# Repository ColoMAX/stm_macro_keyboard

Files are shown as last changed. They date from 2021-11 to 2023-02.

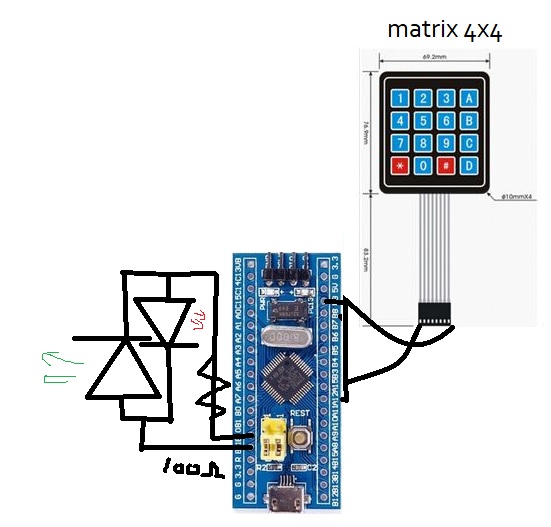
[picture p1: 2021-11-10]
design/draft_schemetic.jpg

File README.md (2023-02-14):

To build needs platformio. Rest can be read in src/main.cpp

Casing just plain PLA and 4 M2 bolts.
Glued some large nuts on the inside to weight down
and some hotglue on the bolts to make it less slippery.

# Building

The macro definitions can be given during the build-process via a cli. Or it can be done via the header file in source.
For the latter the last line of the platformio.ini files needs to be commented out.

It is recommended to use the maple dfu bootloader. In this repo a copy of [maple bootloader](https://github.com/rogerclarkmelbourne/STM32duino-bootloader/blob/df689808b6030280480c0d151ee9c552ecf6b405/binaries/generic_boot20_pc13.bin) is provided.

It is also wise to lock the flash pages using openocd or stlink-utils.

# Operation

settings can be found in `macros_example.hpp`and I recommend changing the timings to your liking.
Device needs stmDuino bootloader.

After the device is flashed and setup it does:
    It first starts the bootloader, after which the red led wil flash (high frequency).
    You may enter a pincode to unlock the device, applying with "*" key.
    If the pincode is correct the green led should light up.
    If wrong, the green and red led should light-up momentarily (orange if led in the same package).
    The pincode can then be retried. After a number of wrong attempts, the device will lockout for some time.
    Then it may be retried. NOTE this lockout can be circumvented once power is lost TODO fix this).
    If then again the attemp limit is reached, the device will wipe its own memory, except of the bootloader.

    If the pincode was correct, the green led will light up.
    Now macros can be used by short pressing any of the buttons, or the device can be switched to numpad mode by a long-press "#".
    One may also whish to go into bootloader mode, then long-hold D. Then de device will restart.
    After some time of inactivity, you will be logged out and the pincode will need to be re-applied.
    This is indicated by the red led starting to flash. You'll get a warning of this timeout by the green led starting to flash.
    You can also manually logout by a long-pres on the "*" button.

    The login timeout can be disabled by going into numpad mode (long-press #) and long-pressing D. The led will momentarily turn green when the timeout is disabled, otherwise red for re-enabled.

# TODO
    Encryption of macros
    use HAL/NVIC
    rewrite pin detection
    write better readme

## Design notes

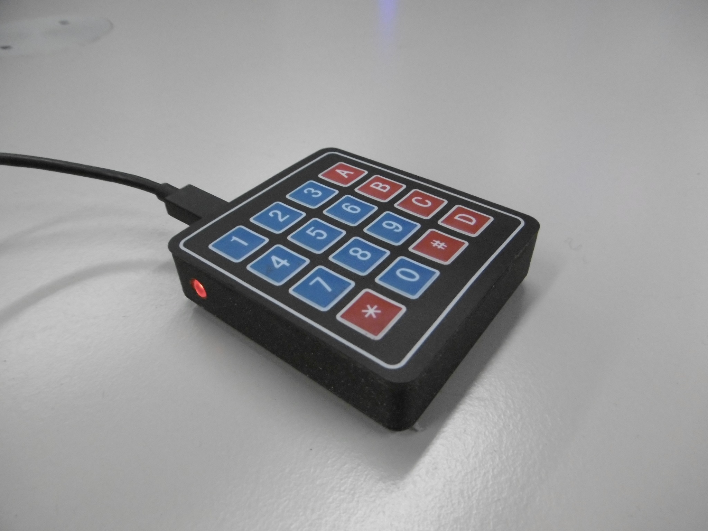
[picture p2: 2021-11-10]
design/stm_macro_keyboard.jpg

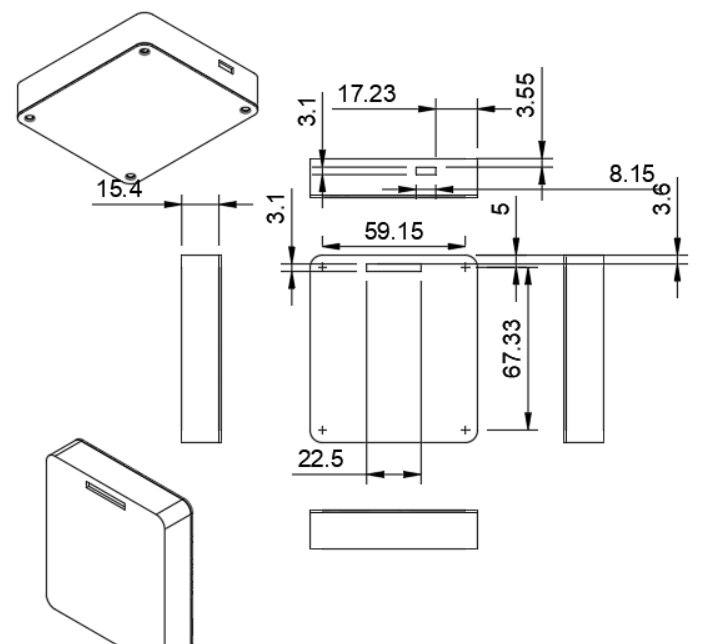
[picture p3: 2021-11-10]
design/case_drawing.png

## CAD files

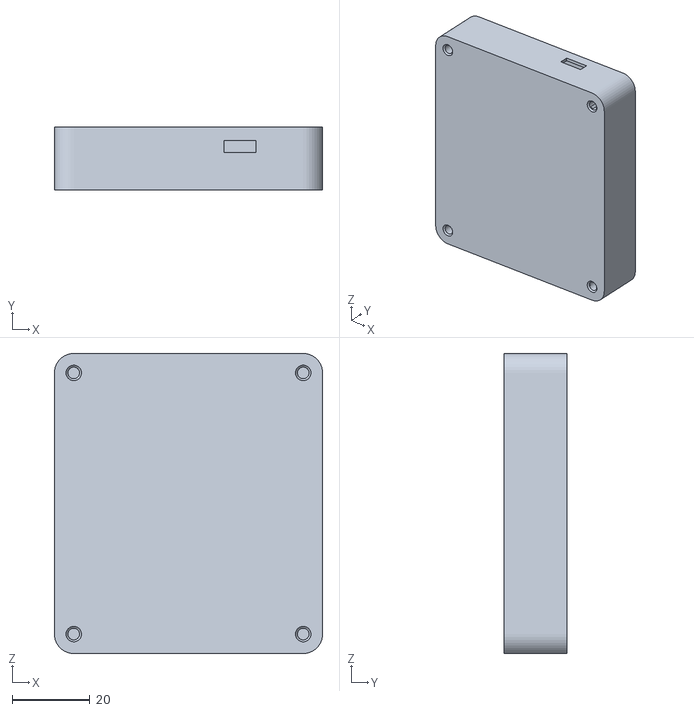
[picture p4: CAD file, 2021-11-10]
design/macro_keyboard.stl
69.2 x 16.3 x 77.3

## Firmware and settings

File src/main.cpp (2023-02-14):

/* colomax at revelation space Den Haag 2021
  A STM32F103C8T6 "bluepill" based macro keyboard with a
  membrane matrix keypad.

  The device needs an usb bootloader for optimal function, which can be
  aquired from https://github.com/rogerclarkmelbourne/STM32duino-bootloader
  ["generic_boot20_pc13.bin"]. This can be uploaded by the STM32CUBEProgrammer
  and a stlinkV2.

  It used the STM32Duino core, which does have a few limitations (at least at
  the time of building this). The Maple core does better in some regard, but has
  other hurdles.
    - On option to use Serial (over USB) is not supported by this core in
  combination with HID. This could be added manually.
    - Option to transfer data by stats-led's of numlock and capslock is not
    supported by the ST-keyboard library. This could be added manually.

  Change the macros in the header, hold D to reset the device to go into
  bootloader mode, which will be exited after 1 second. One will need to dfu
  drivers (maple) to flash via usb.

  The macros will be saved in PLAIN TEXT in the memory of the STM, but the
  device can be put in write-only mode. Unfortunately there are known
  vulnerability's.

  You'll have to put in a pincode after connecting the device to a computer, and
  after 10 minutes of inactivity as a safety precaution.

  The code can be optimized further, as well as be made more secure. Security
  can be enhanced by using an encryption method for the macros and pincode.
  Another method is that the pincode IS the key to the encryption of the macros.
  Optimization can be applied on how the keys are being registered.

  Major improvement would be to create a global FSM.
  Also mutiple pages/tabs could be incorporated of macros by
   for example holding down a macro key, you go to a new page/mode
  with different macros mappings. Or by utilizing the four
  rightsize buttons as page select buttons.
  Thus creating 256 or 36 macros buttons instead of 16.

*/

#include <Arduino.h>
#include <CircularBuffer.h>
#include <Keyboard.h>
#include <Keypad.h>
#include <stm32f1xx_hal_cortex.h>

// not used yet
// #include "mbedtls/config.h"
// #include <mbedtls/blowfish.h>

#include <macros_example.hpp>

#define expr 0

// experimental eeprom.
// does show weird behaviour, so disabled.
#if expr
#include "eewl.h"
#else
#endif

Keypad keypadObj = Keypad(makeKeymap(hexaKeys), rowPins, colPins, ROWS, COLS);

CircularBuffer<char, sizeof(psk) - 1> buffer;

volatile unsigned long lastSeen = 0;
volatile bool initialized = false;
volatile bool numlock_litteral = false;

volatile int psk_false_count = 0;
volatile int psk_false_count_last = 0;
volatile bool disable_timeout = false;

#if expr
struct data_saved {
  int count;
  int count_last;
} cs = {0, 0};
EEWL pC(cs, FLASH_PAGE_SIZE / sizeof(cs), 0););
#endif

enum led_on { repeat, none, red, green, orange };
enum green_blink_state { green_start_blink, green_end_blink, green_stable };

void enable_flash_read_protection();
void system_wipe();
void led_driver(led_on which = repeat);
void print_macro(KeypadEvent key);
void psk_handle(KeypadEvent key);
void keypadEvent(KeypadEvent key);
void logout_warning(unsigned long* last_seen_minor, led_on color);
void blinker_handler(bool initialized);

void setup() {
  if (READ_PROTECTION) enable_flash_read_protection();
#if expr
  EEPROM.begin();
#endif

  lastSeen = millis();
  Keyboard.begin();

  pinMode(PIN_LED_BUILTIN, OUTPUT);
  BILED(pinMode(PIN_ANODE_RED, OUTPUT));
  BILED(pinMode(PIN_ANODE_GREEN, OUTPUT));

  keypadObj.setDebounceTime(DEBOUCE_TIME);
  keypadObj.addEventListener(keypadEvent);
}

void loop() {
  keypadObj.getKeys();  // needed for eventListener,  ;(
  if (disable_timeout) lastSeen = millis();

  if (!disable_timeout && initialized && PSKTIMEOUT &&
      (millis() - lastSeen) >= PSKTIMEOUT) {
    initialized = false;
    buffer.clear();
    // led_driver(red);
  }

  blinker_handler(initialized);
  // led_driver();
}

/**
 * @brief Enable the flash read protection.
 * Takes reset-by-power to take effect.
 *
 */
void enable_flash_read_protection() {
  HAL_FLASH_Unlock();
  HAL_FLASH_OB_Unlock();
  FLASH_OBProgramInitTypeDef pOBInit_for_readprot;
  HAL_FLASHEx_OBGetConfig(&pOBInit_for_readprot);
  // no protection
  if (pOBInit_for_readprot.RDPLevel == OB_RDP_LEVEL_0) {
    // enable protection
    pOBInit_for_readprot.OptionType = OPTIONBYTE_RDP;
    pOBInit_for_readprot.RDPLevel = OB_RDP_LEVEL_1;
    HAL_FLASHEx_OBProgram(&pOBInit_for_readprot);
    HAL_FLASH_OB_Launch();
  }
  HAL_FLASH_OB_Lock();
  HAL_FLASH_Lock();
}

__RAM_FUNC HAL_StatusTypeDef
HAL_FLASHEx_Erase(FLASH_EraseInitTypeDef* pEraseInit, uint32_t* PageError);
__RAM_FUNC HAL_StatusTypeDef HAL_FLASH_Lock();
__RAM_FUNC void HAL_NVIC_SystemReset();

__RAM_FUNC void system_wipe() {
  HAL_FLASH_Unlock();

  // wipe all except bootloader
  uint32_t PageError;
  FLASH_EraseInitTypeDef S_erase{
      .TypeErase = FLASH_TYPEERASE_PAGES,
      .Banks = FLASH_BANK_1,
      .PageAddress = USER_PROGRAM_START,
      // static_assert(IS_FLASH_NB_PAGES())
      .NbPages = (FLASH_START_LAST_PAGE - USER_PROGRAM_START) /
                 FLASH_PAGE_SIZE  // FIXME may be wrong
  };
  HAL_FLASHEx_Erase(&S_erase, &PageError);
  HAL_FLASH_Lock();
  HAL_NVIC_SystemReset();
}

/**
 * @brief low level led_driver, for external and internal.
 * Arduino style.
 * @param which enum led_on. for orange needs frequent calls.
 */
void led_driver(led_on which) {
  static led_on lastState = which;
  static led_on lastColor = none;
  if (which == repeat) {
    which = lastState;
  }

  switch (which) {
  red_driver:
  case red:
    BILED(digitalWrite(PIN_ANODE_RED, HIGH));
    BILED(digitalWrite(PIN_ANODE_GREEN, LOW));
    digitalWrite(PIN_LED_BUILTIN, LOW);
    lastColor = red;
    break;
  green_driver:
  case green:
    BILED(digitalWrite(PIN_ANODE_RED, LOW));
    BILED(digitalWrite(PIN_ANODE_GREEN, HIGH));
    digitalWrite(PIN_LED_BUILTIN, HIGH);
    lastColor = green;
    break;
  none_driver:
  case none:
    BILED(digitalWrite(PIN_ANODE_RED, LOW));
    BILED(digitalWrite(PIN_ANODE_GREEN, LOW));
    digitalWrite(PIN_LED_BUILTIN, HIGH);
    lastColor = none;
    break;
  orange_driver:
  case orange:
    if (lastColor == green) {
      goto red_driver;
    } else {
      goto green_driver;
    }
    break;
    default:
      // dont care, should not be possible
      break;
  }
}

/**
 * @brief write out macro via keyboard.
 *
 * @param key Registered key on numpad. (char)
 */
void print_macro(KeypadEvent key) {
  // brute force search.
  for (int i = 0; i < ROWS; i++) {
    for (int j = 0; j < COLS; j++) {
      if (hexaKeys[i][j] == key) {
        Keyboard.print(maps[i][j]);
        return;
      }
    }
  }
}

/**
 * @brief Check updated pincode, set initialized if correct, and light up led.
 * Pincode is a circular buffer.
 * @param key Registered key on numpad. (char)
 */
void psk_handle(KeypadEvent key) {
  buffer.push(key);
  // only once "*" is pressed, the pincode is checked
  if (buffer.isFull() && buffer.last() == psk_end_char) {
    bool passwordCorrect;
    for (int i = 0; i < buffer.size(); i++) {
      passwordCorrect = buffer[i] == psk[i];
      if (!passwordCorrect) break;
    }
    if (passwordCorrect) {
      led_driver(green);
      initialized = true;
      psk_false_count_last = psk_false_count = 0;
#if expr
      cs.count = psk_false_count;
      pC.put(cs);
#endif
    } else {
#if expr
      pC.get(cs);
      psk_false_count = cs.count;
#endif

      psk_false_count++;
#if expr
      cs.count = psk_false_count;
      pC.put(cs);
#endif
      if (psk_false_count > 0 && psk_false_count % psk_lockout_max == 0) {
        if (psk_false_count % psk_wipe_count == 0) {
          system_wipe();
        } else {
          led_driver(red);
          unsigned long last_time = millis();
          // block for some time
          while ((millis() - last_time < psk_lockout_time)) {
            yield();
          }
        }
      }
    }
  }
}

/**
 * @brief handles keypress events.
 *
 * @param key Registered key on numpad. (char)
 */
void keypadEvent(KeypadEvent key) {
  // TODO clean by use of fsm
  static bool switched_mode = false;

  switch (keypadObj.getState()) {
    case IDLE:
      break;
    case PRESSED:
      break;
    case RELEASED:
      lastSeen = millis();
      if (initialized) {
        if (switched_mode) {
          switched_mode = false;
          return;
        }
        // macro mode
        if (!numlock_litteral) {
          print_macro(key);
        } else {
          // numpad mode.
          Keyboard.write(key);
        }
      } else {
        // pincode mode
        psk_handle(key);
      }
      break;

    case HOLD:
      switch (key) {
        case '#':  // switch between numpad and macro mode
          if (initialized) {
            numlock_litteral = !numlock_litteral;
            switched_mode = true;
          }
          break;
        case 'D':
          if (!initialized | !numlock_litteral) {
            // reset and enter bootloader.
            HAL_NVIC_SystemReset();
          } else {
            switched_mode = true;
            disable_timeout = !disable_timeout;
            led_on color = disable_timeout ? green : red;
            unsigned long now = millis();
            // block
            while ((millis() - now) < 500) {
              yield();
              led_driver(color);
            }
          }
          break;
        case '*':  // logout
          initialized = false;
          break;
        default:
          break;
      }
  }
}

/**
 * @brief Handle initialized -macro mode green led functions.
 *
 * @param last_seen_minor last led change time (ms)
 */
void logout_warning(unsigned long* last_seen_minor, led_on color) {
  static green_blink_state gstate = green_start_blink;
  // almost out of time?
  if (PSKTIMEOUT && (millis() - lastSeen) < PSKTIMEOUT_WARNING ||
      disable_timeout) {
    // nah
    led_driver(color);
  } else {
    // ALMOST OUT OF TIME!
    switch (gstate) {
      case green_start_blink:
        led_driver(none);
        if ((millis() - *last_seen_minor) >= 100) {
          gstate = green_end_blink;
          *last_seen_minor = millis();
        }
        break;
      case green_end_blink:  // make sure to wait for one period.
        led_driver(color);
        gstate = green_stable;
        break;
      case green_stable:
        led_driver(color);
        if ((millis() - *last_seen_minor) >= 900) {
          gstate = green_start_blink;
          *last_seen_minor = millis();
        }
        break;
      default:
        break;
    }
  }
}

bool false_handle() {
  static enum { first, start_orange, timeout } state = timeout;
  bool active = true;
  unsigned long current_time = millis();
  static unsigned long last_seen_minor = current_time;

  // led_driver(orange);
  switch (state) {
    case first:
      last_seen_minor = current_time;
      state = start_orange;
      // led_driver(orange);
      // active = true;
      break;
    case start_orange:
      if ((current_time - last_seen_minor > 200)) {
        last_seen_minor = current_time;
        state = timeout;
        psk_false_count_last = psk_false_count;
      }
      led_driver(orange);
      // active = true;
      break;
    case timeout:
      if (psk_false_count_last < psk_false_count) state = first;
      active = false;
      break;
    default:
      state = timeout;
      break;
  }
  return active;
}

/**
 * @brief Overall led controll.
 *
 * @param initialized logged in flag
 */
void blinker_handler(bool initialized) {
  // if bi_led option is turned off, this part is doing a lot
  //    of non-relavent computation
  static unsigned long last_seen_minor = millis();
  static enum {
    first_blink,
    first_blink_end,
    short_pause,
    second_blink,
    second_blink_end,
    long_pause
  } state = long_pause;
  if (initialized) {
    logout_warning(&last_seen_minor, numlock_litteral ? orange : green);
    state = first_blink;

  } else {
    if (!false_handle()) {
      switch (state) {
        case first_blink:
          led_driver(red);
          state = first_blink_end;
          last_seen_minor = millis();
          break;
        case first_blink_end:
          if ((millis() - last_seen_minor) >= 50) {
            led_driver(none);
            state = short_pause;
            last_seen_minor = millis();
          }
          break;
        case short_pause:
          if ((millis() - last_seen_minor) >= 100) {
            state = second_blink;
            last_seen_minor = millis();
          }
          break;
        case second_blink:
          led_driver(red);
          state = second_blink_end;
          last_seen_minor = millis();
          break;
        case second_blink_end:
          if ((millis() - last_seen_minor) >= 50) {
            led_driver(none);
            state = long_pause;
            last_seen_minor = millis();
          }
          break;
        case long_pause:
          if ((millis() - last_seen_minor) >= BLINK_PERIOD) {
            // led_driver(none);
            state = first_blink;
            last_seen_minor = millis();
          }
          break;
        default:
          state = long_pause;
          break;
      }
    }
  }
}

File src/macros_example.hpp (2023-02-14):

#include <Arduino.h>

/* HOLD "D" to start bootlaoder (reset device), hold "#" to switch between macro
and just keyvalue.
When power applied, first type in passcode ending with a "*" to activate device,
after the timeout, the passswork needs to be put in again. LED will light up
when device is unlocked.   */

// DO NOT ALTER ///////////////////
const byte ROWS = 4;
const byte COLS = 4;
#define xstr(s) str(s)
#define str(s) #s
// DO NOT ALTER ///////////////////

// OPTIONS ///////////////////////////////////////////////////////////

// setting this to false after flashed once with true, will not disable
//      the read protection!
constexpr bool READ_PROTECTION = true;  // enable flash read protection

// enable the use of external led's (green and red)
#define enable_bi_led true

// PIN DEFINITIONS
// bi-led
const byte PIN_ANODE_GREEN = PB11;
const byte PIN_ANODE_RED = PB10;

byte rowPins[ROWS] = {PA15, PB3, PB4, PB5};
byte colPins[COLS] = {PB6, PB7, PB8, PB9};

// key labels / numpad mode
const char hexaKeys[ROWS][COLS] = {{'1', '2', '3', 'A'},
                                   {'4', '5', '6', 'B'},
                                   {'7', '8', '9', 'C'},
                                   {'*', '0', '#', 'D'}};

#ifndef USE_SCRIPT_MACROS
// example of macros. For sacurity, the build script includes an interface
// to type in the macro's during buildtime, instead of having it in the source.
const char* maps[ROWS][COLS] = {
    {"1", "2\n", "3", "MyPassworD12"},
    {"cmake3 ..\n", "echo\n", "beep", "B"},
    {"7", "cowsay hi\n", "xclock\n",
     "sudo apt-get update -y && sudo apt-get upgrade -y\n"},
    {"*", "0", "#",
     "ssh -L 3000:login.server.nl:22"
     "usr@login.nl\n"}};
#else
const char* maps[4][4] = {{xstr(MACRO_1_NAME), xstr(MACRO_2_NAME),
                           xstr(MACRO_3_NAME), xstr(MACRO_A_NAME)},
                          {xstr(MACRO_4_NAME), xstr(MACRO_5_NAME),
                           xstr(MACRO_6_NAME), xstr(MACRO_B_NAME)},
                          {xstr(MACRO_7_NAME), xstr(MACRO_8_NAME),
                           xstr(MACRO_9_NAME), xstr(MACRO_C_NAME)},
                          {xstr(MACRO_S_NAME), xstr(MACRO_0_NAME),
                           xstr(MACRO_H_NAME), xstr(MACRO_D_NAME)}};
#endif

// pincode
#define psk_ "1234"
// apply pincode char
#define end_psk *

// number of tries before lockout
const int psk_lockout_max = 5;
// time locked out after psk_lockout_max wrong attempts.
//      Does reset on power reset
const unsigned long psk_lockout_time = 3 * 3600;
// number of lockouts untill flash wipe.
const int psk_wipe_count = 2;

// auto-logout in ms of inactivity:  10 min
const unsigned long PSKTIMEOUT = 10 * 1000 * 60;
// auto-logout warning in ms:  5 min
const unsigned long PSKTIMEOUT_WARNING = PSKTIMEOUT * 0.5;

// DO NOT ALTER ////////////////////////////////////////////////////////
const byte PIN_LED_BUILTIN = PC13;

const unsigned long BLINK_PERIOD = 500;  // ms: 500 ms
const uint DEBOUCE_TIME = 10;            // ms

#define USER_PROGRAM_START 0x08005000
#define FLASH_START_LAST_PAGE 0x0801FC00

#if enable_bi_led
#define BILED(x) x
#else
#define BILED(x)
#endif

static_assert(PSKTIMEOUT > PSKTIMEOUT_WARNING);

const char psk[] = psk_ xstr(end_psk);
const char psk_end_char = xstr(end_psk)[0];
// DO NOT ALTER /////////////////////////////////////////////////////////

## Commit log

2021-11-10 added design files
    [macro_keyboard.stl]
2021-11-11 added timeout warning. added numpad mode orange indicator. refactoring psk and macro printing. fixed fault of uninitilzed acces to numpad mode switch.
    [macros_example.hpp, main.cpp]
2021-11-13 modified pincode struture: time lockout, and device wipe, ending pincode with "*". added led signalling of wrong pincode.
    [macros_example.hpp, main.cpp]
2021-11-13 added timeout disable option. fixed bug with logout warning. added experimental saving of failed attemps, does not function.
    [main.cpp]
2021-11-14 safer macro to device loading
